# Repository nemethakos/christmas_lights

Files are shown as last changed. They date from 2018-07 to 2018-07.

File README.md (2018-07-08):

# Animated Christmas Lights with Arduino.

Project description: http://fritzing.org/projects/christmas-lights

Christmas Lights in Action (https://www.youtube.com/watch?v=RwZ6XnqKiA4 "Christmas Lights in Action")

Christmas Lights in action: https://www.youtube.com/watch?v=RwZ6XnqKiA4

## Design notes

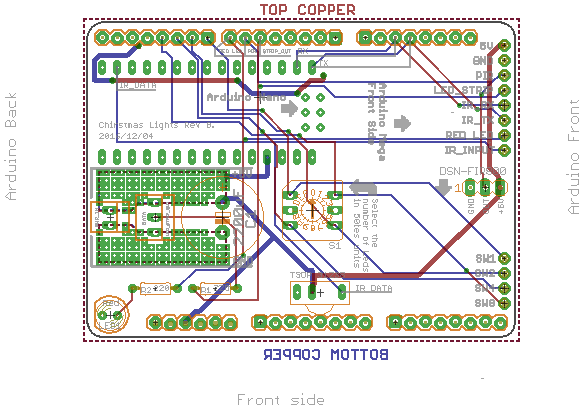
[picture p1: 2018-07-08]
media/top_and_bottom_overview.png

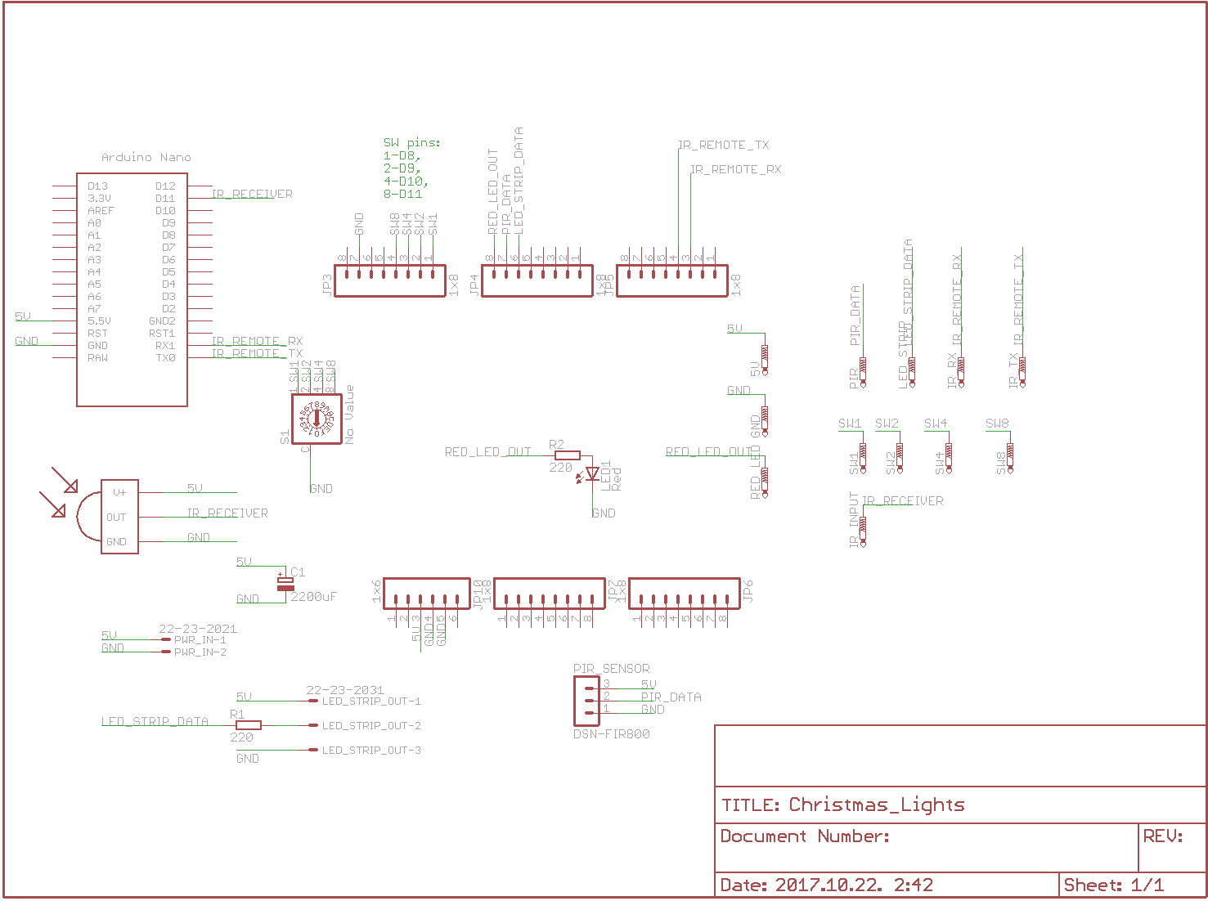
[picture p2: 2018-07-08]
media/schematic.png

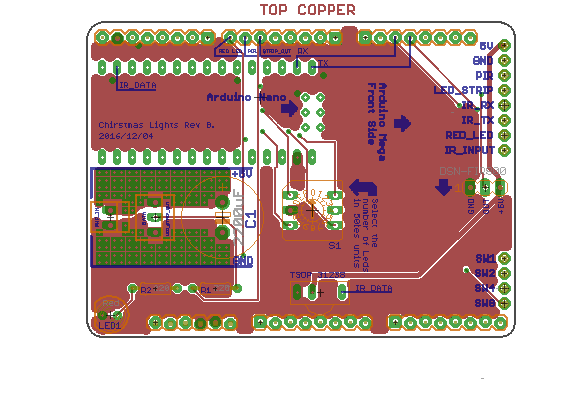
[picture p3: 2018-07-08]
media/top_copper.png

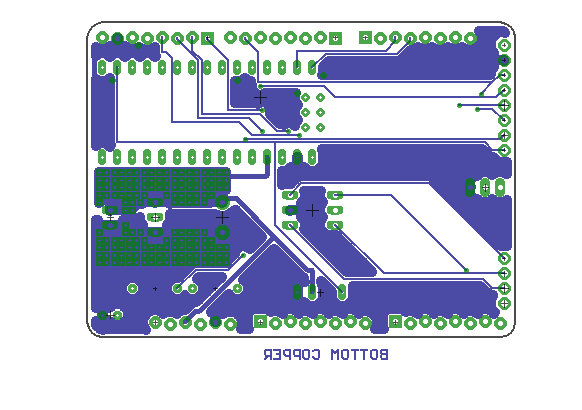
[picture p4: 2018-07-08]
media/bottom_copper.png

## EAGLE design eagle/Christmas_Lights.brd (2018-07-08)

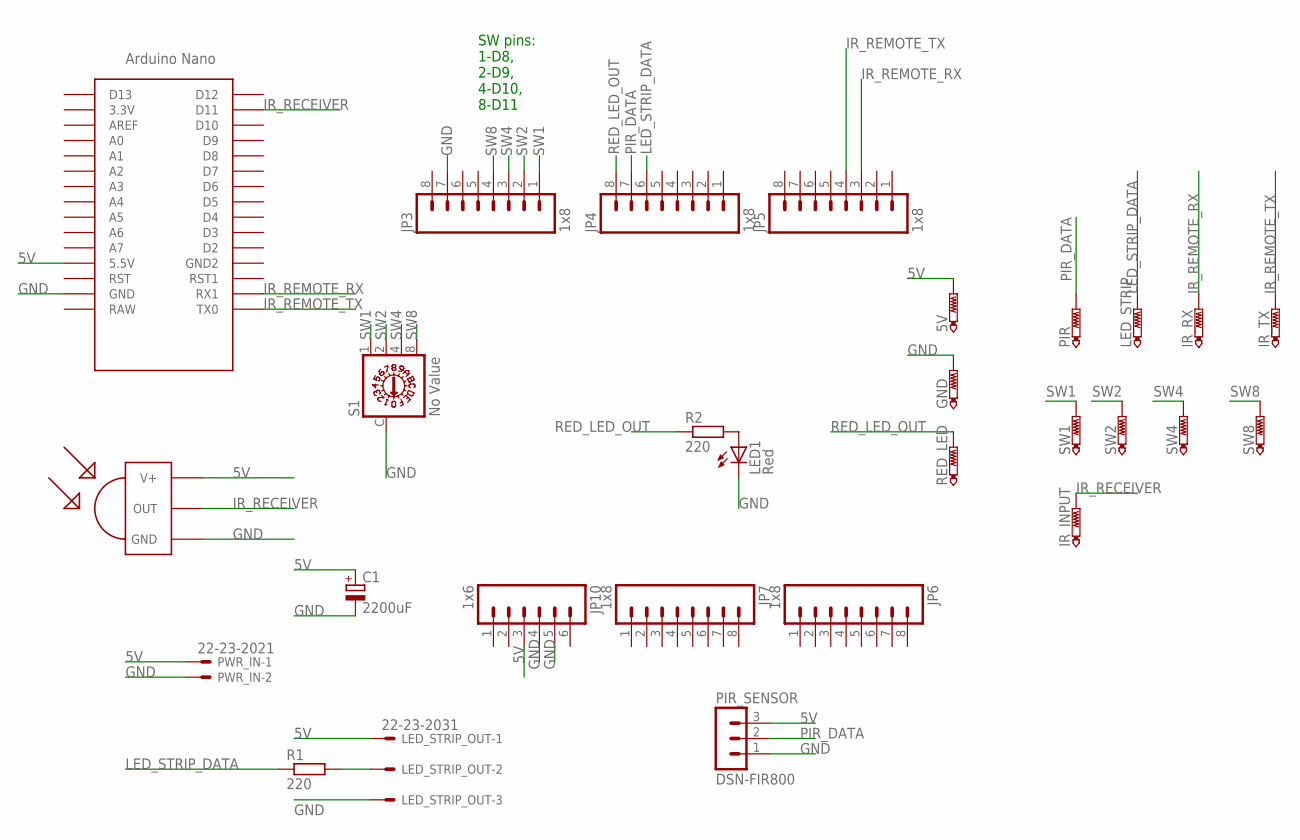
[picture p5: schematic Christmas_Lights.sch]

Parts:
5V: PTR1PAD1-13; P1-13
C1: 2200uF; E5-13
GND: PTR1PAD1-13; P1-13
IR_INPUT: PTR1PAD1-13; P1-13
IR_RX: PTR1PAD1-13; P1-13
IR_TX: PTR1PAD1-13; P1-13
JP3, JP4, JP5, JP6, JP7: 1x8; 1X08_LOCK
JP10: 1x6; 1X06_LOCK
LED1: Red; LED5MM
LED_STRIP: PTR1PAD1-13; P1-13
LED_STRIP_OUT: 22-23-2031
PIR: PTR1PAD1-13; P1-13
PIR_SENSOR: DSN-FIR800; MA03-1
PWR_IN: 22-23-2021
R1, R2: 220; 0204/7
RED_LED: PTR1PAD1-13; P1-13
S1: No Value; P103
SW1, SW2, SW4, SW8: PTR1PAD1-13; P1-13
TSOP31328: TSOP 31238; TSOP17XX
U$1: NANO

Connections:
5V: 5V.TP, C1.+, JP10.3, LED_STRIP_OUT.1, PIR_SENSOR.3, PWR_IN.1, TSOP31328.V+, U$1.5V (5.5V)
GND: C1.-, GND.TP, JP3.7, JP10.4, JP10.5, LED1.K (C), LED_STRIP_OUT.3, PIR_SENSOR.1, PWR_IN.2, S1.C, TSOP31328.GND, U$1.GND
IR_RECEIVER: IR_INPUT.TP, TSOP31328.OUT, U$1.D11
IR_REMOTE_RX: IR_RX.TP, JP5.3, U$1.RX1
IR_REMOTE_TX: IR_TX.TP, JP5.4, U$1.TX0
LED_STRIP_DATA: JP4.6, LED_STRIP.TP, R1.1
unnamed: LED_STRIP_OUT.2, R1.2
unnamed: LED1.A, R2.2
PIR_DATA: JP4.7, PIR.TP, PIR_SENSOR.2
RED_LED_OUT: JP4.8, R2.1, RED_LED.TP
SW1: JP3.1, S1.1, SW1.TP
SW2: JP3.2, S1.2, SW2.TP
SW4: JP3.3, S1.4, SW4.TP
SW8: JP3.4, S1.8, SW8.TP

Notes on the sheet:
SW pins: 1-D8, 2-D9, 4-D10, 8-D11

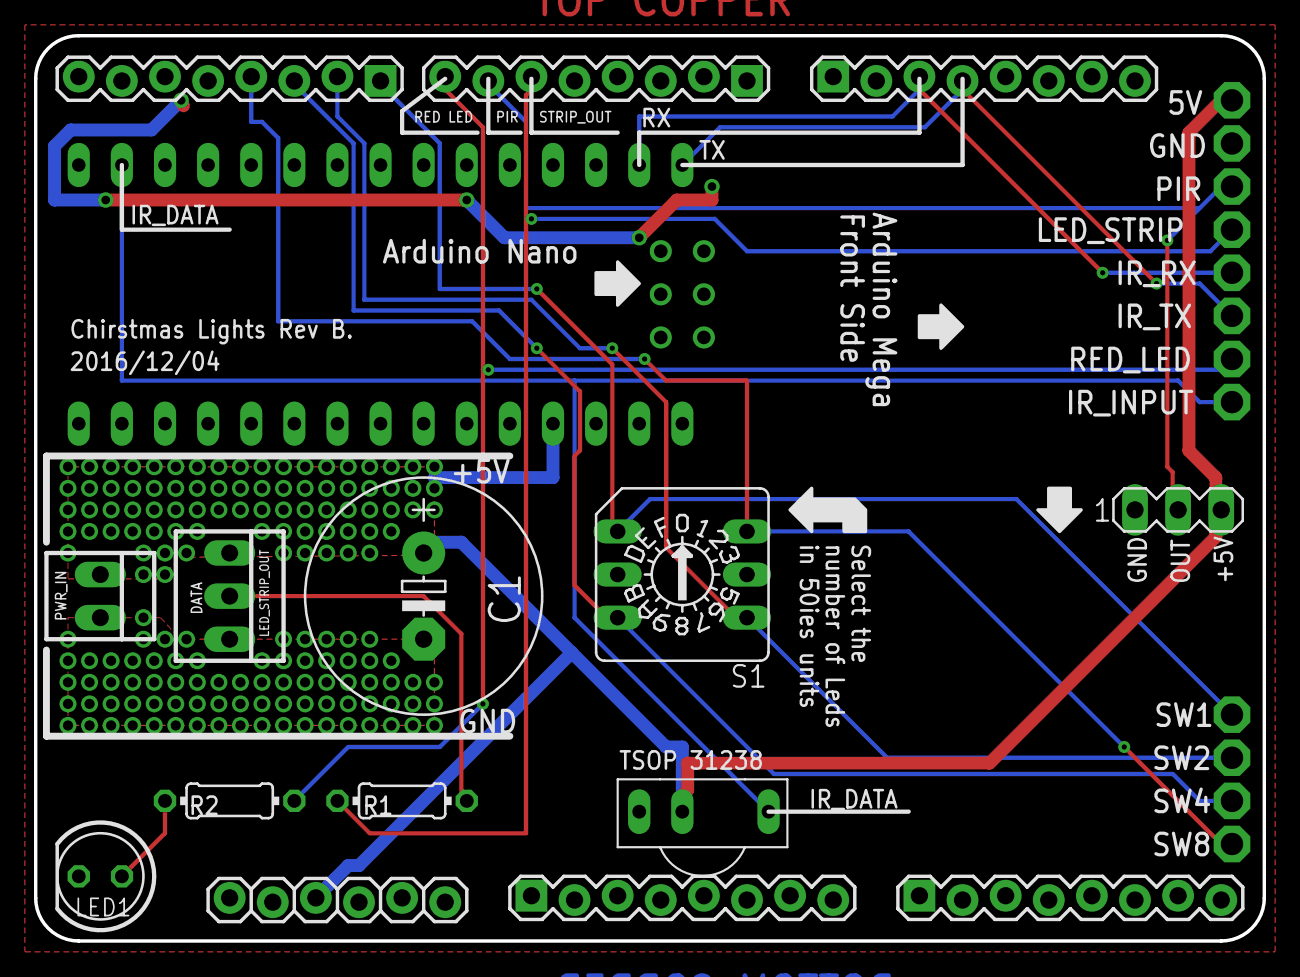
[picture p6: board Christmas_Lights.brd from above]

Board: 2 copper layers, 72.4 x 53.3 mm, 28 parts (0 on the bottom side), 14 nets.

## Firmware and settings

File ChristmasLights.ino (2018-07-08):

//#include "Arduino.h"
#include "Effect.h"
#include <FastLED.h>
#include <IRremote.h>
#include "RemoteCodes.h"
//#include <Streaming.h>

#define SW1_PIN 8
#define SW2_PIN 9
#define SW4_PIN 10
#define SW8_PIN 11


// LED String Data PIN
#define LED_PIN     5
#define COLOR_ORDER RGB
#define CHIPSET     WS2812

#define BRIGHTNESS        0x80
#define FRAMES_PER_SECOND  50

// RED LED
#define RED_PIN    7

// PIR Sensor's pin
#define PIR_PIN    6
#define PIR_AHEAD_TIME 5000;

// UNCOMMENT THIS IF PIR SENSOR IS USED
//#define USE_PIR

// Auto off delay time after the last PIR/IR event
#define AUTO_POWER_OFF_MS (4* 60L * 60L * 1000L)

// IR Receiver's Serial port
#define IR_SERIAL (Serial2)

// Effect States

#define STATE_STOPPING     101
#define STATE_INIT         103
#define STATE_RUN          104

// Application state
#define APP_START          200
#define APP_RUN            201
#define APP_STOP           202
#define APP_STOPPING       203

#define DEBUG_ENABLED


#ifdef DEBUG_ENABLED
#define DEBUGT(text) Serial.print(F(text));
#define DEBUGTLN(text) Serial.println(F(text));
#define DEBUGV(text, value) Serial.print(F(text)); Serial.print(": "); Serial.println(value);
#define DEBUGVO(value) Serial.print(value);
#else
#define DEBUGT(text)
#define DEBUGTLN(text)
#define DEBUGV(text, value)
#define DEBUGVO(value)
#endif

#define MIN_BRIGHTNESS 5
#define MAX_BRIGHTNESS 255
#define BRIGHTNESS_STEP 5


CRGB leds[MAX_LED_NUM];

int numLeds = 0;

int effectIndex = 0;

int appState = APP_STOP;

int effectState = STATE_INIT;



boolean oldPIR = false;
boolean newPIR = false;
boolean pirMotionOn = false;

unsigned long onLastPushed = 0;

unsigned long nextEffectLastPushed = 0;
unsigned long prevEffectLastPushed = 0;


// time should pass between the pressing of ON/OFF button
unsigned long ON_OFF_PUSH_TIME_TRESHOLD = 1000;

int lastButtonCode = -1;

int nextEffectIndex = -1;
int switchToEffect = -1;

boolean on = false;

int brightness = BRIGHTNESS;

unsigned long lastPIREvent = 0;
unsigned long lastIREvent = 0;

// red status led brightness value is determined using the maximum of the three levels (standby, pir, ir)
long standbyLevel; // 8.8 level of standby
long standbySpeed; // -STANDBY_SPEED, 0, +STANDBY_SPEED
long pirLevel; // 8.8 level of pir
long irLevel; // 8.8 level of ir
long irCounter; // frame counter for ir on/off

// all off levels are 0
#define STANDBY_LEVEL ((long)63 << 8) // level of standby level when on
#define STANDBY_LEVEL_SPEED ((long)5 << 7) // speed of standby level change
#define PIR_LEVEL ((long)1 << 8) // level of PIR sensor when on
#define IR_LEVEL ((long)63 << 8) // level of IR pulse when on
#define IR_FRAMES (long)(1) // number of frames when the IR pulse is displayed


bool autoPowerOffEnabled = false;

void initRedLed();
void autoPowerOff();

void initSwitch() {
  pinMode(SW1_PIN, INPUT_PULLUP);
  pinMode(SW2_PIN, INPUT_PULLUP);
  pinMode(SW4_PIN, INPUT_PULLUP);
  pinMode(SW8_PIN, INPUT_PULLUP);
}

int readSwitch() {
  int value = 0;

  int sw1 = digitalRead(SW1_PIN);
  int sw2 = digitalRead(SW2_PIN);
  int sw4 = digitalRead(SW4_PIN);
  int sw8 = digitalRead(SW8_PIN);
  /*
  Serial.print(sw1);
  Serial.print(sw2);
  Serial.print(sw4);
  Serial.println(sw8);
  */

  value = sw1;
  value += sw2 << 1;
  value += sw4 << 2;
  value += sw8 << 3;
  return 15 - value;
}

void setupNumberOfLeds() {
  initSwitch();
  int switchValue = readSwitch();
  if (switchValue == 0) {
    switchValue = 1;
    DEBUGTLN("Switch value is set to 0, using 1 instead!");
  }

  numLeds = switchValue * 50;
  if (numLeds > MAX_LED_NUM) {
    numLeds = MAX_LED_NUM;
    DEBUGT("Switch is set to a greater value, than maximum number of leds supported!");
  }

  DEBUGV("Number of LED", numLeds);

}

/*
 * Setup
 */
void setup() {
  FastLED.addLeds<CHIPSET, LED_PIN, COLOR_ORDER>(leds, MAX_LED_NUM);
  FastLED.setCorrection( TypicalLEDStrip );
  FastLED.setDither(0);
  FastLED.setBrightness( brightness );

#ifdef DEBUG_ENABLED
  Serial.begin(9600);
#endif
  IR_SERIAL.begin(9600);

  pinMode(PIR_PIN, INPUT);

  lastPIREvent = millis();
  lastIREvent = millis();
  autoPowerOffEnabled = false;

  setupNumberOfLeds();
  random16_add_entropy( random());
  initRedLed();
  DEBUGTLN("Setup finished");
  /* Serial.println(sizeof(CRGBPalette256));
   Serial.print("fire: "); Serial.println(sizeof(FIRE_EFFECT_DATA));
   Serial.print("blink: "); Serial.println(sizeof(BLINK_EFFECT_DATA));
   Serial.print("lumu: "); Serial.println(sizeof(LUMU_EFFECT_DATA));
   Serial.print("trail: "); Serial.println(sizeof(TRAIL_EFFECT_DATA));
   Serial.print("single candle: "); Serial.println(sizeof(CANDLE_DATA));
   Serial.print("line: "); Serial.println(sizeof(LINE_EFFECT_DATA));
  */

}

#define MAX_PIR_EVENT_TRESHOLD  15000

void loop()
{

  unsigned long startTime = millis();

  autoPowerOff();
  readIRReceiver();
  readPIRSensor();
  updateRedLed();


  if (appState == APP_START) {
    DEBUGTLN("App state: APP_START");
    effectIndex = 0;
    effectState = STATE_INIT;
    appState = APP_RUN;
  }
  else if (appState == APP_RUN) {
    // DEBUGV("On: ", on);

    if (!on) {
      appState = APP_STOPPING;
      effectState = STATE_STOPPING;
      autoPowerOffEnabled = false;
      standbySpeed = STANDBY_LEVEL_SPEED;
    }

  }
  else if (appState == APP_STOP) {
    // DEBUGT("App state: APP_STOP");
    if (on) {
      appState = APP_START;
      autoPowerOffEnabled = true;
      standbySpeed = -STANDBY_LEVEL_SPEED;
    }
  }

  if (appState != APP_STOP) {
    runEffect();
  }

  unsigned long finishTime = millis();

  unsigned long updateInterval = (finishTime - startTime);

  long delayTime = (1000 / FRAMES_PER_SECOND) - updateInterval;

  if (delayTime > 0) {
    long ellapsedAfterPIR = millis() - lastPIREvent;
    if (ellapsedAfterPIR < MAX_PIR_EVENT_TRESHOLD) {
      long _delayTime = ((delayTime * ellapsedAfterPIR << 8) / MAX_PIR_EVENT_TRESHOLD) >> 8;

      delayTime = _delayTime;
    }
    FastLED.delay(delayTime);
  }

}

void autoPowerOff() {
  if (autoPowerOffEnabled) {
    unsigned long currentTimeMS = millis();
    unsigned long ellapsedPIR = currentTimeMS - lastPIREvent;
    unsigned long ellapsedIR = currentTimeMS - lastIREvent;

    boolean pir = (ellapsedPIR > AUTO_POWER_OFF_MS);
    boolean ir = (ellapsedIR > AUTO_POWER_OFF_MS);

    /*
        Serial.print("ellapsedPIR");
        Serial.println(ellapsedPIR);
        Serial.print("ellapsedIR");
        Serial.println(ellapsedIR);
        Serial.print("pir");
        Serial.println(pir);
        Serial.print("ir");
        Serial.println(ir);
        Serial.print("AUTO_POWER_OFF_MS");
        Serial.println(AUTO_POWER_OFF_MS);
    */
    if (pir && ir) {
      on = false;
      DEBUGTLN("Auto Power Off");
    }
  }
}

int prevEffectState = -1;

void printEffectState(int effectState) {
  if (effectState == 101) {
    DEBUGT("STOPPING");
  }
  else if (effectState == 103) {
    DEBUGT("INIT");
  }
  else if (effectState == 104) {
    DEBUGT("RUN");
  }
  else {
    DEBUGT("Unknown!");
  }
}


void runEffect() {

  Effect currentEffect = effects[effectIndex];

  if (prevEffectState != effectState) {
    printEffectState(prevEffectState);
    DEBUGT(" -> ");
    printEffectState(effectState);

    DEBUGVO(effectIndex);
    prevEffectState = effectState;
  }

  if (effectState == STATE_INIT) {

    currentEffect.init();
    effectState = STATE_RUN;
  }


  if (effectState == STATE_RUN) {
    //DEBUGT("Effect state: STATE_RUN");
  }
  if (effectState == STATE_RUN && nextEffectIndex != -1) {
    effectState = STATE_STOPPING;
  }

  boolean stopFlag = false;
  if (effectState == STATE_STOPPING) {
    stopFlag = true;
    effectState = STATE_STOPPING;
  }

  boolean stopped = currentEffect.update(stopFlag);

  if (stopped && appState == APP_STOPPING) {
    appState = APP_STOP;
    return;
  }

  if (stopped && on && appState == APP_RUN) {
    if (nextEffectIndex != -1) {
      effectIndex = nextEffectIndex;
      nextEffectIndex = -1;
    }
    else {
      effectIndex = 0;
    }
    effectState = STATE_INIT;
  }
}


void readIRReceiver() {
  if (IR_SERIAL.available() > 0) {


    int buttonCode = IR_SERIAL.parseInt();
    // consume end of lines
    while (IR_SERIAL.read() != '\n');

    if (buttonCode != -1) {

      DEBUGV("IR Remote Button code", buttonCode);

      irCounter = IR_FRAMES;
      lastIREvent = millis();
    }

    if (buttonCode == BUTTON_ON_OFF && (millis() - onLastPushed) > ON_OFF_PUSH_TIME_TRESHOLD ) {
      on = !on;
      onLastPushed = millis();
      DEBUGV("IR ON: ", on);
    }

    if (buttonCode == BUTTON_CHANNEL_DOWN && effectState == STATE_RUN && (millis() - nextEffectLastPushed) > ON_OFF_PUSH_TIME_TRESHOLD ) {
      nextEffectIndex = effectIndex + 1;
      if (nextEffectIndex > NUM_EFFECTS - 1) {
        nextEffectIndex = 0;
      }
      nextEffectLastPushed = millis();
      DEBUGV("UP", nextEffectIndex);
    }
    else if (buttonCode == BUTTON_CHANNEL_UP && effectState == STATE_RUN && (millis() - prevEffectLastPushed) > ON_OFF_PUSH_TIME_TRESHOLD) {

      nextEffectIndex = effectIndex - 1;
      if (nextEffectIndex < 0) {
        nextEffectIndex = NUM_EFFECTS - 1;
      }
      prevEffectLastPushed = millis();
      DEBUGV("DOWN", nextEffectIndex);
    }



    if (buttonCode == BUTTON_VOLUME_UP) {
      if (brightness < MAX_BRIGHTNESS) {
        brightness += BRIGHTNESS_STEP;
        if (brightness > MAX_BRIGHTNESS) {
          brightness = MAX_BRIGHTNESS;
        }
        FastLED.setBrightness( brightness );
      }
    }
    else if (buttonCode == BUTTON_VOLUME_DOWN) {
      if (brightness > BRIGHTNESS_STEP) {
        brightness -= BRIGHTNESS_STEP;
        FastLED.setBrightness( brightness );

      }
      else {
        brightness = MIN_BRIGHTNESS;
        FastLED.setBrightness( brightness );
      }
    }

    if (buttonCode != lastButtonCode) {
      lastButtonCode = buttonCode;
    }
  }
}



unsigned long start ;

void readPIRSensor() {
#ifdef USE_PIR
  newPIR = digitalRead(PIR_PIN);
  if (newPIR != oldPIR) {


    if (newPIR) {
      start = millis();
      pirMotionOn = true;
      lastPIREvent = millis();
      DEBUGT("PIR ON");
    }
    else {
      pirMotionOn = false;
      DEBUGT("PIR OFF");
      //lastPIREvent = millis();
    }

    oldPIR = newPIR;
  }
#endif
}

/*
* Updates the Red led
*/

void initRedLed() {
  standbyLevel = STANDBY_LEVEL;
  pirLevel = 0;
  irLevel = 0;
  irCounter = 0;
  pinMode(RED_PIN, OUTPUT);
}

void setRedLed(byte value) {
  analogWrite(RED_PIN, value);
}

void updateRedLed() {

  standbyLevel += standbySpeed;
  //Serial.println(standbySpeed);
  if (standbyLevel > STANDBY_LEVEL) {
    standbyLevel = STANDBY_LEVEL;
    standbySpeed = 0;
  }
  if (standbyLevel < 0) {
    standbyLevel = 0;
    standbySpeed = 0;
  }
  if (pirMotionOn) {
    pirLevel = PIR_LEVEL;
  }
  else {
    pirLevel = 0;
  }

  if (irCounter > 0) {
    irLevel = IR_LEVEL;
    irCounter--;
  }
  else {
    irLevel = 0;
  }

  long level = standbyLevel;
  if (level < pirLevel) {
    level = pirLevel;
  }
  if (level < irLevel) {
    level = irLevel;
  }

  setRedLed((level >> 8) & 0xff);

}

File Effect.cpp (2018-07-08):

#include "Effect.h"


Effect effects[] = {
  //{&initBlur, &updateBlur},
  {&initCandle, &updateCandle},
  {&initFire, &updateFire},
  {&initTrail1, &updateTrail1},
  {&initSpark, &updateSpark},
  {&initBlink, &updateBlink},
  {&initLUMU, &updateLUMU},
  {&initWhite, &updateWhite},
  {&initSet, &updateSet},

  //  {&initLine, &updateLine}
};

const CRGB LUMU_COLORS[] = {
  0xFF0000,
  0xFF0000,

  0x800080,
  0x800080,

  0x0000FF,
  0x0000FF,

  0x008080,
  0x008080,

  0x00FF00,
  0x00FF00,

  0x808000,
  0x808000

  /*
  CRGB::DeepPink,
  CRGB::MediumVioletRed,
  CRGB::Crimson,
  CRGB::Red,
  CRGB::OrangeRed,
  CRGB::Brown,
  CRGB::Maroon,
  CRGB::DarkOliveGreen,
  CRGB::Olive,
  CRGB::OliveDrab,
  CRGB::SeaGreen,
  CRGB::ForestGreen,
  CRGB::Green,
  CRGB::DarkGreen,
  CRGB::Blue,
  CRGB::Navy,
  CRGB::DarkViolet,
  CRGB::DarkMagenta,
  CRGB::Indigo,
  CRGB::DarkSlateBlue,
  CRGB::Black*/
};

#define LUMU_COLORS_LENGTH (sizeof(LUMU_COLORS) / sizeof(CRGB))

CRGBPalette256  heatMap;
void printCRGB(CRGB color) {
  Serial.print("r: ");
  Serial.print(color.r);
  Serial.print(", g:");
  Serial.print(color.g);
  Serial.print(", b:");
  Serial.println(color.b);

}

void printBuffer() {
  for (int i = 0; i < BLUR_SIDE_LENGTH; i++) {
    Serial.print("i=");
    Serial.print(i);
    Serial.print(", color: ");
    printCRGB(u.blurEffectData.buffer[i]);
  }
}


CRGB updateBuffer(CRGB newValue) {
  //Serial.print("-------------------------newValue=");
  //printCRGB(newValue);
  CRGB result = u.blurEffectData.buffer[BLUR_SIDE_LENGTH - 1];
  for (int i = BLUR_SIDE_LENGTH - 1; i > 0; i--) {
    u.blurEffectData.buffer[i] = u.blurEffectData.buffer[i - 1];
  }
  u.blurEffectData.buffer[0] = newValue;
  //printBuffer();
  return result;
}




unsigned long gauss[] = {16, 62, 99, 62, 16};

void blur() {
  CRGB pixel = CRGB::Black;
  unsigned long r;
  unsigned long g;
  unsigned long b;
  unsigned long _r;
  unsigned long _g;
  unsigned long _b;
  byte index;

  for (int i = 0; i < numLeds + BLUR_SIDE_LENGTH; i++) {
    r = 0;
    g = 0;
    b = 0;

    index = 0;
    for (int j = i - BLUR_SIDE_LENGTH; j <= i + BLUR_SIDE_LENGTH; j++) {


      if (j > 0 && j < numLeds) {
        _r = leds[j].r * gauss[index];
        _g = leds[j].g * gauss[index];
        _b = leds[j].b * gauss[index];

        r += _r;
        g += _g;
        b += _b;
      }

      index++;
    }
    r = r / BLUR_WIDTH;
    g = g / BLUR_WIDTH;
    b = b / BLUR_WIDTH;

    r += 127;
    g += 127;
    b += 127;

    r = r >> 8;
    if (r > 0xff) {
      r = 0xff;
    };
    g = g >> 8;
    if (g > 0xff) {
      g = 0xff;
    };
    b = b >> 8;
    if (b > 0xff) {
      b = 0xff;
    };

    /*
        Serial.print("r: ");
        Serial.print(r);
        Serial.print(", g:");
        Serial.print(g);
        Serial.print(", b:");
        Serial.println(b);
    */
    pixel.r = (byte)r;
    pixel.g = (byte)g;
    pixel.b = (byte)b;

    CRGB value = updateBuffer(pixel);
    int writeBackIndex = i - BLUR_SIDE_LENGTH;
    if (writeBackIndex >= 0) {
      /*   Serial.print("i=");Serial.print(i);
         Serial.print(",wbi=");Serial.println(writeBackIndex);
         printCRGB(pixel);*/
      leds[writeBackIndex] = value;
    }
  }
}




boolean updateBlur(boolean stop) {
  CHSV hsv = CHSV(random(256), 255, 255);
  CRGB rgb;
  hsv2rgb_spectrum(hsv, rgb);


  int index = random(numLeds);
  int length = random(numLeds - index);
  for (int i = 0; i < length; i++) {
    leds[index] += rgb;
  }

  //  blur();

  // if (random(10) == 0) {
  // darker(1);
  //}
  darker(1);
  FastLED.show(); // display this frame

  return false;
}


void initBlur() {
  for (int i = 0; i < numLeds; i++) {
    leds[i] = CRGB(0, 0, 0);
  }
}

//-----------------------
// WHITE test effect
//------------------------

boolean updateWhite(boolean stop) {
  if (!stop) {
    if (u.setEffectData.phase < 255) {
      u.setEffectData.phase += 5;
    }

    for (int i = 0; i < numLeds; i++) {
      leds[i] = CRGB(u.setEffectData.phase, u.setEffectData.phase, u.setEffectData.phase);

    }

    FastLED.show(); // display this frame
    return false;
  }
  else {

    darker(5);
    FastLED.show(); // display this frame

    if (sumLeds() == 0) {
      return true;
    }
    return false;
  }
}

void initWhite() {
  u.setEffectData.phase = 0;
}

//-----------------------
// SET test effect
//------------------------

boolean updateSet(boolean stop) {
  if (!stop) {
    if (u.setEffectData.phase < 255) {
      u.setEffectData.phase += 5;
    }
    for (int i = 0; i < numLeds; i++) {
      leds[i] = CRGB(u.setEffectData.phase / 25, u.setEffectData.phase / 25, u.setEffectData.phase / 25);
      if ((i + 1) % 50 == 0) {
        leds[i] = CRGB(u.setEffectData.phase, u.setEffectData.phase, u.setEffectData.phase);
      }
    }
    FastLED.show(); // display this frame
    return false;
  }
  else {

    darker(5);
    FastLED.show(); // display this frame

    if (sumLeds() == 0) {
      return true;
    }
    return false;
  }
}

void initSet() {
  u.setEffectData.phase = 0;
}

//--------------------------------------------------------------------------------------------------
// LINE
//--------------------------------------------------------------------------------------------------
void initOneLine(int lineIndex);
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
